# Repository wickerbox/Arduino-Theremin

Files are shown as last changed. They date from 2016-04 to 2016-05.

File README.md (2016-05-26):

# Arduino Theremin v1

Playing music by waving your hands over a rangefinder for pitch and pressing capacitive sense pads for key.

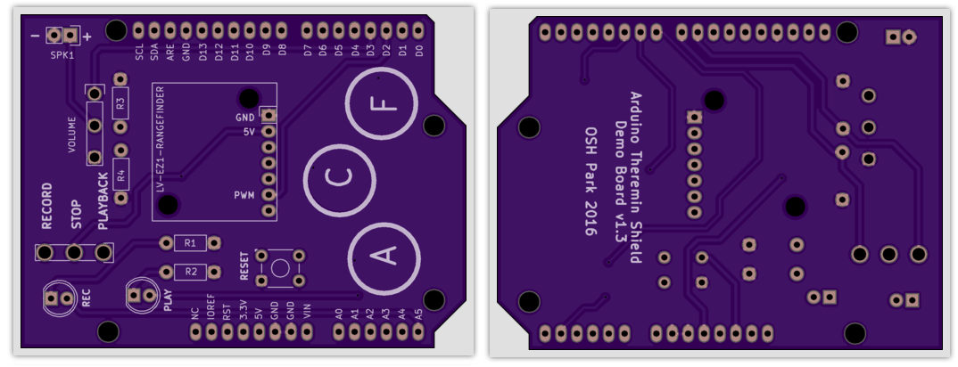
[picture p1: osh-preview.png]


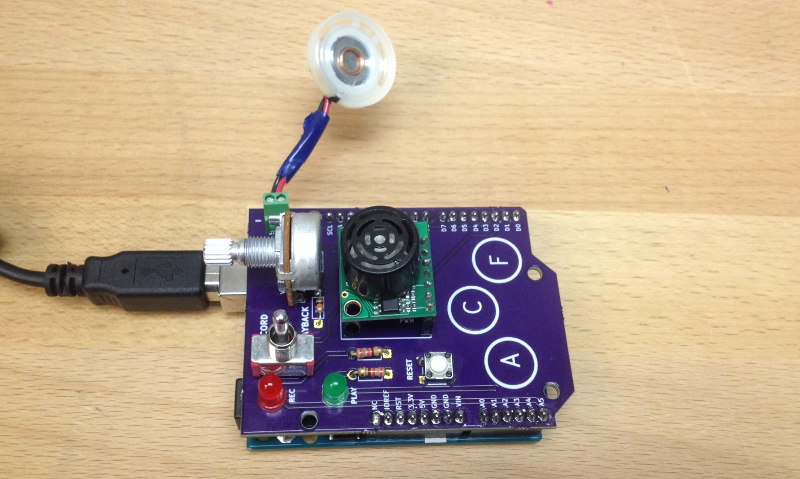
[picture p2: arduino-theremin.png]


## Instructions

1. Program the Arduino Uno
1. To use it, the Uno needs some sort of power, 9V or 5V or whatever.
1. Press the 'reset' button. The red and green lights will blink.
1. The switch normally sits in the 'OFF' position.
1. Flip the switch to the RECORD position to play and record a tune.
1. Move one hand vertically between 1 and about 10 inches above the rangefinder.
1. Use the other hand to press the capacitive sense pads to choose a key.
1. When you're done with a tune, flip the switch back to OFF.
1. When you want to play back the tune, flip the switch to PLAYBACK.
1. The tune will play once through. 
1. To play it again, flip the switch to OFF and then to PLAYBACK.
1. To record a new tune, flip the switch to RECORD, which erases the old tune.

## Bill of Materials

I've <a href="https://oshpark.com/shared_projects/u5dTU3Mx">shared the boards at OSH Park</a>. You can buy a set of three for $29.50. 

|Refdes|Qty|Description|Digikey|
|---|---|---|---|
|J1|1|CONN HEADER FEMALE .100" SNGL STR 8POS|952-1823-ND|
|LED1|1|LED RED DIFF 5MM ROUND T/H|1125-1188-ND|
|LED2|1|LED GRN DIFF 5MM ROUND T/H|1125-1184-ND|
|R1,R2|2|RES 220 OHM 1/4W 5% CF MINI|S220QCT-ND|
|R3,R4|2|RES 10K OHM 1/4W 5% CF MINI|S10KQCT-ND|
|RV1|1|POT 10K OHM 1/5W PLASTIC LINEAR|987-1301-ND|
|SP1|1|SPEAKER 8 OHM .25W 23MM ROUND|458-1124-ND|
|SW1|1|SWITCH TACTILE SPST-NO 0.05A 24V|SW400-ND|
|SW2|1|SWITCH TOGGLE SPDT 5A 120V|EG2377-ND|
|U1|1|CONN HEADER MALE .100" SNGL STR 40POS|S1012EC-40-ND|

The best way to place U1 is to buy one 40-position header is the cheapest option (about $0.50) and snap it apart into the sections you need.

|Refdes|Qty|Description|Adafruit|
|---|---|---|---|
|P1|1|Maxbotix Ultrasonic Rangefinder LV-EZ1|Product 172|

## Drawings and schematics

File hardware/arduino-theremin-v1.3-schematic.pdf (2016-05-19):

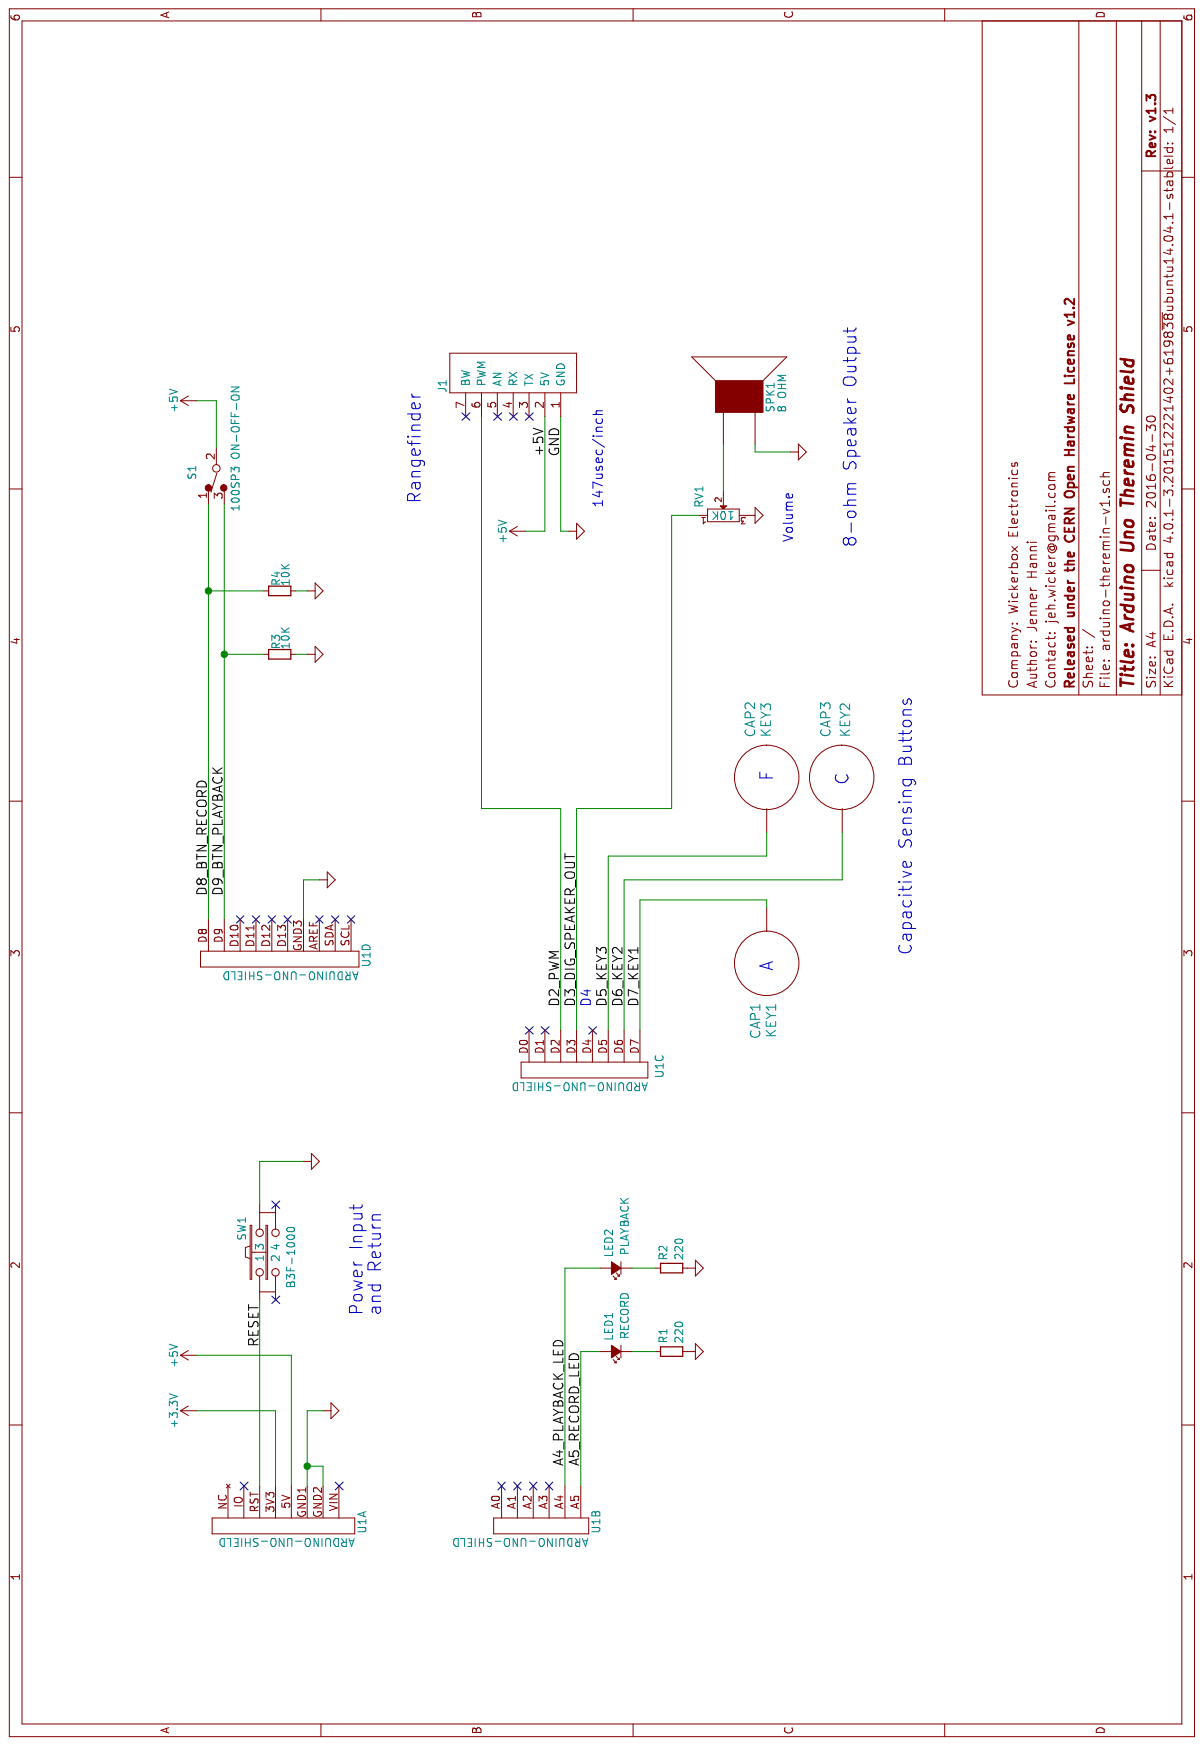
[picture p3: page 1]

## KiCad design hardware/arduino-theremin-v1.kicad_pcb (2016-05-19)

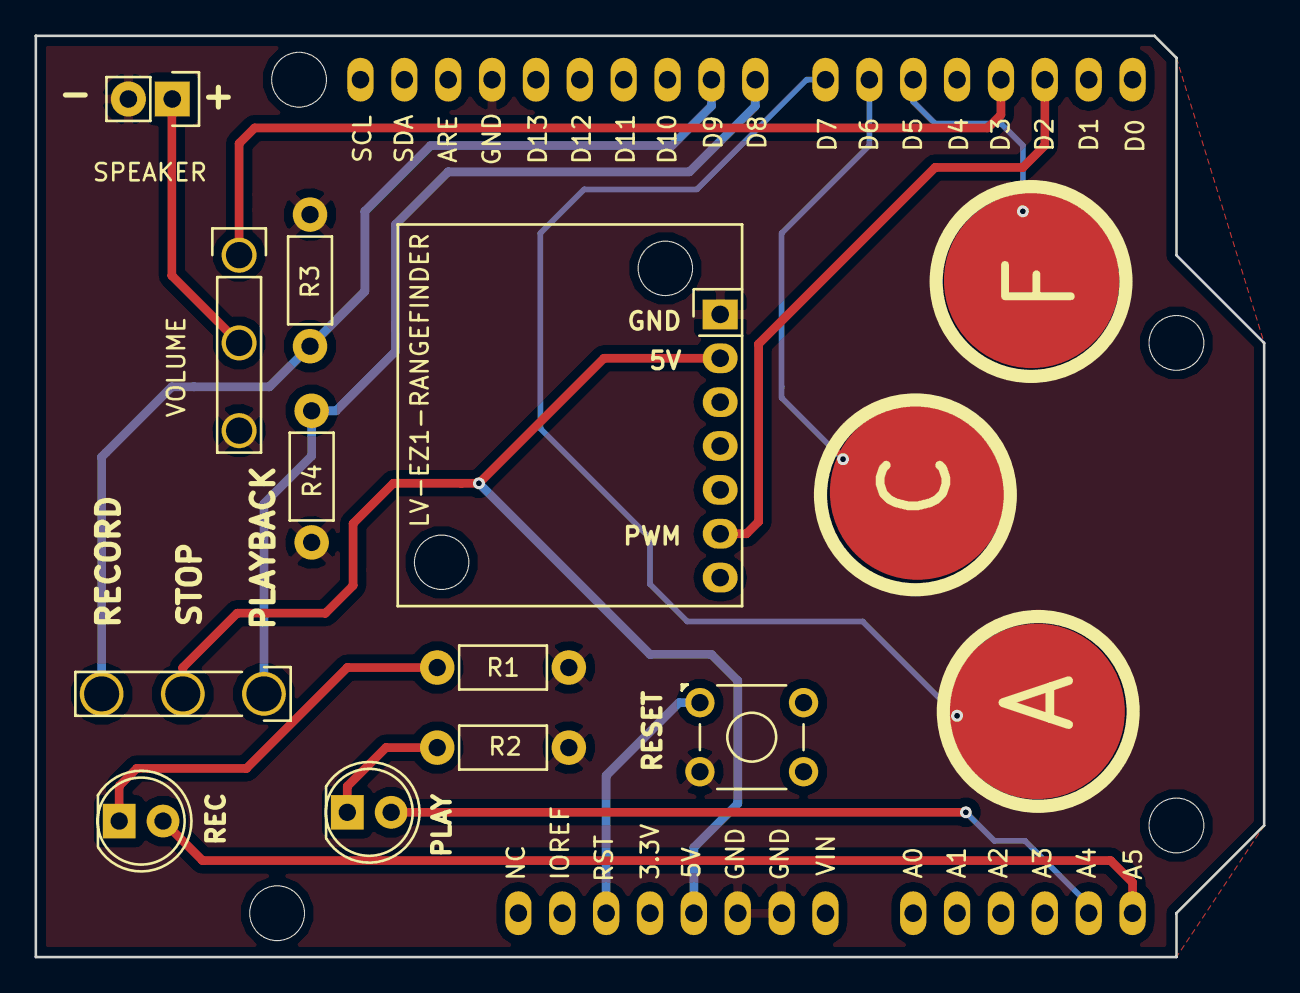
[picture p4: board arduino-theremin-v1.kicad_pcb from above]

Board: 2 copper layers, 71.1 x 53.3 mm, 15 parts (0 on the bottom side), 15 nets.

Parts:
A: KEY1; CAPSENSE-CIRCLE-D10
C: KEY2; CAPSENSE-CIRCLE-D10
F: KEY3; CAPSENSE-CIRCLE-D10
LV-EZ1-RANGEFINDER: LV-EZ1-RANGEFINDER; LV_EZ1_Rangefinder
PLAY: PLAYBACK; LED-5MM-2PIN
R1, R2: 220; Resistor_Horizontal_RM7mm
R3, R4: 10K; Resistor_Horizontal_RM7mm
REC: RECORD; LED-5MM-2PIN
RESET: B3F-1000; SW-B3F-10XX
S1: 100SP3 ON-OFF-ON; SW-100SP3
SPEAKER: 8 OHM; OSTVN02A150
U1: ARDUINO-UNO-SHIELD; ARDU-UNOSHIELD
VOLUME: 10K; P160-TRIMPOT

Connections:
+5V: LV-EZ1-RANGEFINDER.2, S1.2, U1.5V
/A4_PLAYBACK_LED: PLAY.2, U1.A4
/A5_RECORD_LED: REC.2, U1.A5
/D2_PWM: LV-EZ1-RANGEFINDER.6, U1.D2
/D3_DIG_SPEAKER_OUT: U1.D3, VOLUME.1
/D5_KEY3: F.1, U1.D5
/D6_KEY2: C.1, U1.D6
/D7_KEY1: A.1, U1.D7
/D8_BTN_RECORD: R4.1, S1.1, U1.D8
/D9_BTN_PLAYBACK: R3.1, S1.3, U1.D9
/RESET: RESET.1, U1.RST
GND: LV-EZ1-RANGEFINDER.1, R1.2, R2.2, R3.2, R4.2, RESET.3, SPEAKER.2, U1.GND1, U1.GND2, U1.GND3, VOLUME.3
unnamed: R1.1, REC.1
unnamed: PLAY.1, R2.1
unnamed: SPEAKER.1, VOLUME.2

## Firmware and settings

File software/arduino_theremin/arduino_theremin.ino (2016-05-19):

// by Jenner Hanni
// http://github.com/wicker
//
// Based on code from Bruce Allen 
// http://playground.arduino.cc/mMain/MaxSonar
//
// Based on code from Tone example
// https://www.arduino.cc/en/Tutorial/ToneMelody?from=Tutorial.Tone
//
// Using the readCapacitivePin function from Mario Becker, Alan Chatham, and others
// http://playground.arduino.cc/Code/CapacitiveSensor

#include "pitches.h"

#define START    0
#define RECORD   1
#define HOLD     2
#define PLAYBACK 3

#define A 0
#define C 1
#define F 2

#define MAXNOTE  7
#define MAXTUNECOUNT 299

// set up state
uint8_t state = START;
uint8_t last_state = START;

// these arrays contain each key's set of notes
int noteArray_A[8] = {NOTE_A1,NOTE_A2,NOTE_A3,NOTE_A4,NOTE_A5,
                      NOTE_A6,NOTE_A7};
int noteArray_C[8] = {NOTE_C1,NOTE_C2,NOTE_C3,NOTE_C4,NOTE_C5,
                      NOTE_C6,NOTE_C7};
int noteArray_F[8] = {NOTE_F1,NOTE_F2,NOTE_F3,NOTE_F4,NOTE_F5,
                      NOTE_F6,NOTE_F7};

// huge array to hold the current tune
// largest note in pitches.h is 4978
// 2^16 = 65536
uint16_t current_tune[300];
uint16_t current_tune_count = 0;
uint16_t total_current_notes = 0;
uint16_t curr_key = A;
uint16_t note_delay = 50; // in milliseconds
uint16_t note = 0;

// inputs
const uint8_t recordPin = 8;
const uint8_t playbackPin = 9;
const uint8_t pwmPin = 2;
const uint8_t aKeyPin = 7;
const uint8_t cKeyPin = 6;
const uint8_t fKeyPin = 5;

// outputs
const uint8_t speakerPin = 3;
const uint8_t playbackLEDPin = A4;
const uint8_t recordLEDPin = A5;

// process input from the rangefinder
long pulse, inches, cm;

uint8_t readCapacitivePin(int pinToMeasure) {

  // Variables used to translate from Arduino to AVR pin naming
  volatile uint8_t* port;
  volatile uint8_t* ddr;
  volatile uint8_t* pin;
  // Here we translate the input pin number from
  //  Arduino pin number to the AVR PORT, PIN, DDR,
  //  and which bit of those registers we care about.
  byte bitmask;
  port = portOutputRegister(digitalPinToPort(pinToMeasure));
  ddr = portModeRegister(digitalPinToPort(pinToMeasure));
  bitmask = digitalPinToBitMask(pinToMeasure);
  pin = portInputRegister(digitalPinToPort(pinToMeasure));
  // Discharge the pin first by setting it low and output
  *port &= ~(bitmask);
  *ddr  |= bitmask;
  delay(1);
  uint8_t SREG_old = SREG; //back up the AVR Status Register
  // Prevent the timer IRQ from disturbing our measurement
  noInterrupts();
  // Make the pin an input with the internal pull-up on
  *ddr &= ~(bitmask);
  *port |= bitmask;

  // Now see how long the pin to get pulled up. This manual unrolling of the loop
  // decreases the number of hardware cycles between each read of the pin,
  // thus increasing sensitivity.
  uint8_t cycles = 17;
  if (*pin & bitmask) { cycles =  0;}
  else if (*pin & bitmask) { cycles =  1;}
  else if (*pin & bitmask) { cycles =  2;}
  else if (*pin & bitmask) { cycles =  3;}
  else if (*pin & bitmask) { cycles =  4;}
  else if (*pin & bitmask) { cycles =  5;}
  else if (*pin & bitmask) { cycles =  6;}
  else if (*pin & bitmask) { cycles =  7;}
  else if (*pin & bitmask) { cycles =  8;}
  else if (*pin & bitmask) { cycles =  9;}
  else if (*pin & bitmask) { cycles = 10;}
  else if (*pin & bitmask) { cycles = 11;}
  else if (*pin & bitmask) { cycles = 12;}
  else if (*pin & bitmask) { cycles = 13;}
  else if (*pin & bitmask) { cycles = 14;}
  else if (*pin & bitmask) { cycles = 15;}
  else if (*pin & bitmask) { cycles = 16;}

  // End of timing-critical section; turn interrupts back on if they were on before, or leave them off if they were off before
  SREG = SREG_old;

  // Discharge the pin again by setting it low and output
  //  It's important to leave the pins low if you want to 
  //  be able to touch more than 1 sensor at a time - if
  //  the sensor is left pulled high, when you touch
  //  two sensors, your body will transfer the charge between
  //  sensors.
  *port &= ~(bitmask);
  *ddr  |= bitmask;
  return cycles;
}

void startupBlinkLEDs() {
  digitalWrite(recordLEDPin, HIGH);
  digitalWrite(playbackLEDPin, HIGH);
  delay(200);
  digitalWrite(recordLEDPin, LOW);
  digitalWrite(playbackLEDPin, LOW);
  delay(200);
  digitalWrite(recordLEDPin, HIGH);
  digitalWrite(playbackLEDPin, HIGH);
  delay(200);
  digitalWrite(recordLEDPin, LOW);
  digitalWrite(playbackLEDPin, LOW);
  delay(200);      
}

void setup() {

  Serial.begin(9600);
  Serial.println("Begin.");

  pinMode(recordPin, INPUT);
  pinMode(playbackPin, INPUT);
  pinMode(pwmPin, INPUT);
  pinMode(aKeyPin, INPUT);
  pinMode(cKeyPin, INPUT);
  pinMode(fKeyPin, INPUT);
  pinMode(speakerPin, OUTPUT);
  pinMode(playbackLEDPin, OUTPUT);
  pinMode(recordLEDPin, OUTPUT);

  state = START;
  
}

void loop() {

  switch(state) {
    case START:
      startupBlinkLEDs();
      break;
    case RECORD:

      // if we just entered the record state, clear the current tune
      if (last_state != RECORD) {
        for (current_tune_count = 0; current_tune_count < MAXTUNECOUNT; current_tune_count++)
          current_tune[current_tune_count] = 0;
        current_tune_count = 0;
      }
      
      digitalWrite(recordLEDPin, HIGH);
      digitalWrite(playbackLEDPin, LOW);

      // get note
      pulse = pulseIn(pwmPin, HIGH);
      note = pulse/147;
      if (note > 14)
        note = 14;
      else if (note < 7)
        note = 7;
      note = note - 7;

      // record the note in the correct key
      if (current_tune_count < 299) 
        if (curr_key == A)
          current_tune[current_tune_count++] = noteArray_A[note];
        else if (curr_key == C)
          current_tune[current_tune_count++] = noteArray_C[note];
        else 
          current_tune[current_tune_count++] = noteArray_F[note];

      // play note in correct key
      if (curr_key == A)
        tone(3,noteArray_A[note],1000/8);
      else if (curr_key == C)
        tone(3,noteArray_C[note],1000/8);
      else 
        tone(3,noteArray_F[note],1000/8);

      delay(note_delay);

      break;
    case HOLD:
      // if we just came here from record, let's capture the number of
      // notes in our current tune, in case we want to play it back
      if (last_state == RECORD) {
        total_current_notes = current_tune_count - 1;
      }
      
      digitalWrite(recordLEDPin, LOW);
      digitalWrite(playbackLEDPin, LOW);

      delay(note_delay);

      break;
    case PLAYBACK:
      // reset the counter so we can play it back once
      // use the 
      if (last_state != PLAYBACK) {
        current_tune_count = 0;
      }
      if (current_tune_count <= total_current_notes) {
        tone(3,current_tune[current_tune_count],1000/8);
        current_tune_count++;
      }
      digitalWrite(recordLEDPin, LOW);
      digitalWrite(playbackLEDPin, HIGH);

      delay(note_delay*2);

      break;
  }


  // change the key based on cap sense input
  if (readCapacitivePin(aKeyPin) > 5)
    curr_key = A;
  else if (readCapacitivePin(cKeyPin) > 5)
    curr_key = C;
  else if (readCapacitivePin(fKeyPin) > 5)
    curr_key = F;
  else
    curr_key = curr_key;

  // change state based on input switch
  last_state = state;
  if (digitalRead(recordPin) == HIGH)
    state = RECORD;
  else if (digitalRead(playbackPin) == HIGH)
    state = PLAYBACK;
  else 
    state = HOLD;
    
}

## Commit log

2013-11-30 Just messing around on a Saturday afternoon.
    [avicii-wake_me_up.csv, jesusaur.csv, minimal.csv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]
2013-11-30 Added Arduino sketch.
2013-12-01 Cleaning up repo.
    [avicii-wake_me_up.csv, jesusaur-unmid.csv, jesusaur.csv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]
2016-03-09 Trying out version 1.1 footprint fix.
    [arduino-theremin-v1-B.Cu.gbl, arduino-theremin-v1-B.Mask.gbs, arduino-theremin-v1-B.SilkS.gbo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]
2016-04-30 v1.3, based on wickerlib, fixes the reversed rangefinder. Ordered from OSH Park.
    [arduino-theremin-v1.kicad_pcb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]
2016-04-30 Updated BOM and preview image for v1.3.
2016-05-15 Reorg. Remove ancient code. Change default KiCad settings.
    [arduino-theremin-v1.kicad_pcb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]
2016-05-15 Ported Arduino Theremin to use Wickerlib.
    [arduino-theremin-v1.kicad_pcb, arduino-theremin-v1.sch]
2016-05-19 Added text on schematic to indicate A, C, F keys.
    [arduino-theremin-v1.sch]
2016-05-19 Looks like Rec/PB pins are backwards in schematic. Fixed in code, added states to sketch.
    [arduino_theremin.ino]
2016-05-19 Updated board file to match correct names for D8 and D9 PLAYBACK and RECORD. All done.
    [arduino-theremin-v1.kicad_pcb, arduino-theremin-v1.sch]

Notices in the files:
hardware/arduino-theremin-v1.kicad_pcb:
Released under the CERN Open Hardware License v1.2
